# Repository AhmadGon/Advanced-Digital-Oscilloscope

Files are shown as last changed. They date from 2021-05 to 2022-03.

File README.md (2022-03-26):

# Advanced-Digital-Oscilloscope
A new version of digital oscilloscope project that contains debouncers on all buttons and switches, also the ability to make a screenshot and stream it to PC, 2 Channels scope, ability to measure frequencies and amplitudes, pause button and more 

Project implemented on DE2-115 FPGA board

ScopeScreenShot2
ScopeScreenShot
ScopeScreenShot

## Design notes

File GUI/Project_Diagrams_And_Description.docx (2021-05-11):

### Project diagrams and description

# Digital Oscilloscope

### Top Level

Memory

CPU

ADC

VGA

Top Level Module

- VGA driver.
- ADC driver.
- NIOS driver.
- Memory driver:
1. SDRAM
2. M9K SRAM

VGA driver

Vsync/Hsync

Pixel Clock

H_Pixel/V_Pixel

Sync_n/Blank_n

Module exports

Clock/Reset

Module imports

This module imports Clock and reset signals from Top Level module, these signals are then used to generate the necessary Video Graphics Array signals such as Vertical synchronization signal (Vsync) and Horizontal synchronization signal (Hsync), this module also generates a 25MHz pixel clock for displaying 640*480 resolution images at 60Hz refresh rate, no PLL used here since the base frequency of the used FPGA (DE2-115) is 50MHz and we can use a simple counter to generate the 25MHz signal.

The H_Pixel and V_Pixel signals are Horizontal and Vertical counters for scaning the entire monitor frame, these two signals use new terminology than the H_counter/V_counter signals used in the previous Digital Oscilloscope project uploaded on GitHub, the H_Pixel has a range from 0-639 and the V_Pixel has a range from 0-479.

Sync_n/Blank_n active low signals control the ADV7123 DAC to avoid sending data to the blanking area on the screen.

Assigned to Ahmad

### Top Level Description

ADC driver

ADC_CLK

CS

Module exports

Clock/Reset

Module imports

The AD7352 is a differential input, dual ADC intergrated circuit, this dual-ADC has 3MSPS sampling rate with 12-bit accuarcy which is excellent accuarcy,

This ADC needs maximum power supply voltage of 2.75V which is considered low voltage, that means that the power consumption by this ADC is quite low.

The digital oscilloscope is built using based on this ADC

Assigned to Mustafa

Serial_DATA

### Top Level Description

CPU driver

Module exports

Module imports

The NIOS CPU is a soft processor that can be included in any FPGA project, this RISC(Reduced Instruction Set) CPU can be added as an IP Core through Qsys System Integration Tool in Quartus software.

The CPU comes with different cores such as F core and E core for different targets, the E core for example is the economic core drivative of the processor which consume less logic elements and resources but at speed cost.

The NIOS is used in this project as a way to communicate with external PC host to transfer saved data in SDRAM to hard drive, the data stored in SDRAM is screen shot pixel data.

Assigned to Ahmad

### Top Level Description

Memory driver

The memory driver is divided into two main parts, the first one is used to manage the memory within the scope, storing analog data, frequency, images and others, while the second part (the SDRAM part) is specially used to store screen shots, the screen shots should be divided into two parts, the colormap of the image and pixel index for each screen shot or we could just save it as 24-bit data structure which will cost us more memory but in return will make things easier to read by NIOS.

This module has alot of input and output ports with high data trafficing, since every clock pulse plays a major role in controlling data paths that is linked to other modules, we can say that the scope heart is in this module.

No exports and imports are drawn since there are alot of them.

Assigned to Mustafa

Assigned to Ahmad

### Top Level Description

To/From SDRAM

Screen shot order

Incoming data, memory mapped reached

To host PC

Controls ADC chip and recieves serial data form the chip

General Storage

Controls

To Screen

I/O

I/O

ADC

VGA

M9K

Avalon Switch Fabric

SDRAM

NIOS

### General Diagram

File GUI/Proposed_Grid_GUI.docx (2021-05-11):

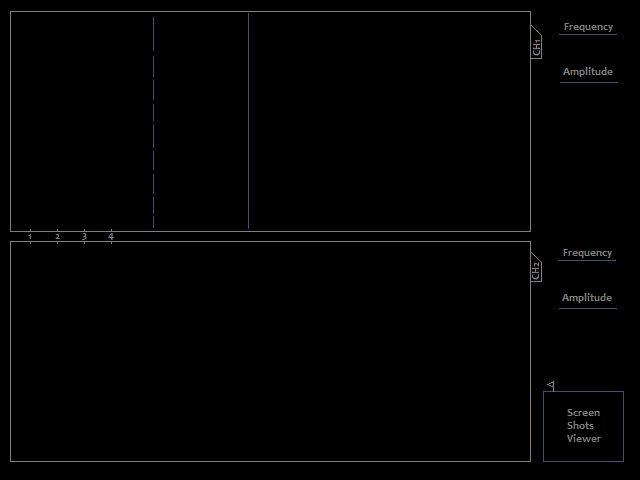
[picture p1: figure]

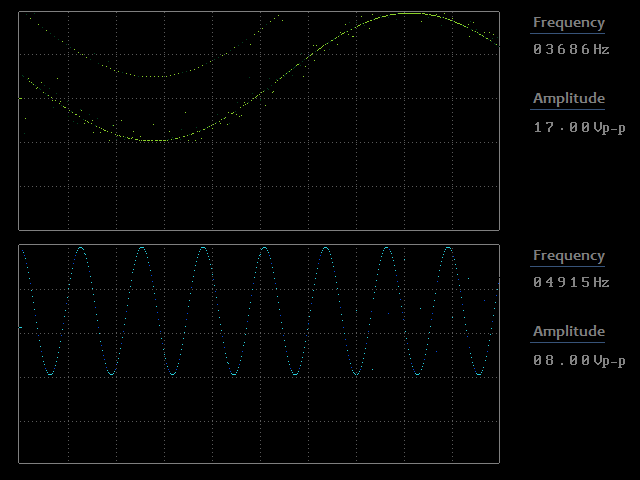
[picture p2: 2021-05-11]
Software/NiosII_Screen_Reader/ScopeScreenShot2.bmp

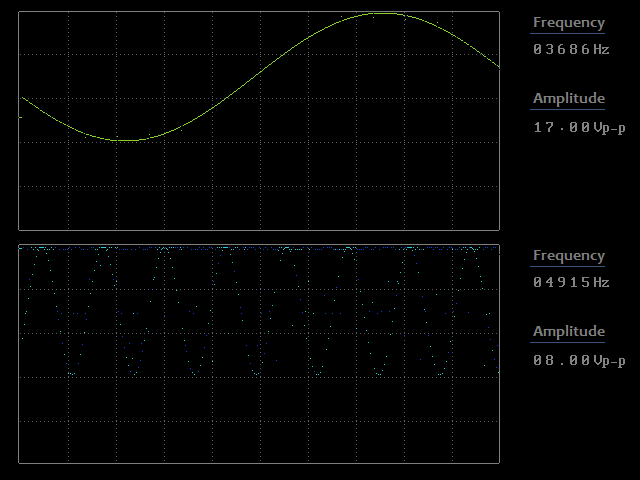
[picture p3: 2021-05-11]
Software/NiosII_Screen_Reader/ScopeScreenShot1.bmp

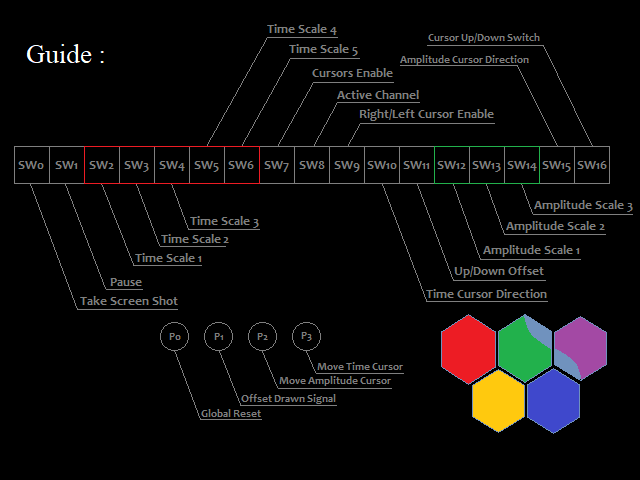
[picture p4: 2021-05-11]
Software/NiosII_Screen_Reader/ScopeScreenShot.bmp

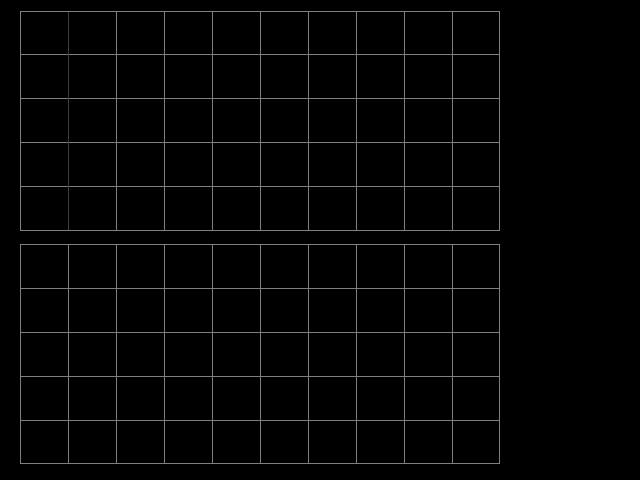
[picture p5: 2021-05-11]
GUI/Proposed_GUI.png

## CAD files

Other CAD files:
db/SRAM_Control_auto_stripped.stp
output_files/stp1.stp
SDRAM_Control.stp
Amplitude_Calculator.stp
db/Amplitude_Calculator_auto_stripped.stp
db/DeBouncer_auto_stripped.stp
TimeScale.stp
db/stp1_auto_stripped.stp
GUI.stp
db/VGA_Controls_auto_stripped.stp
SRAM_Control.stp
db/TimeScale_auto_stripped.stp
DeBouncer.stp
db/GUI_auto_stripped.stp
VGA_Controls.stp
db/SDRAM_Control_auto_stripped.stp

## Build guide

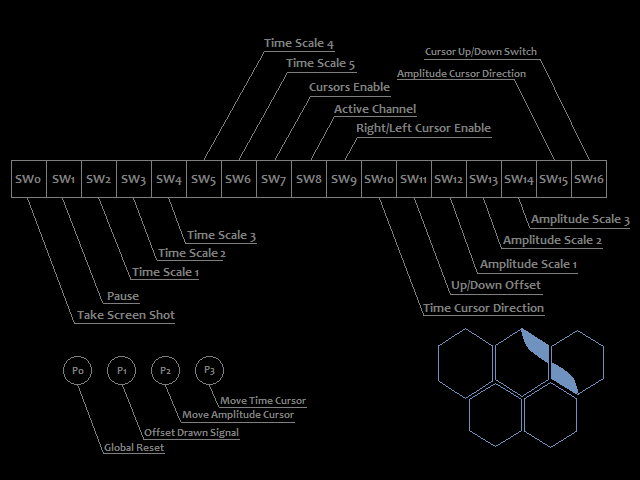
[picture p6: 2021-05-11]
GUI/Guide.png

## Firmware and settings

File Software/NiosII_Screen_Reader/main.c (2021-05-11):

/*
 * Authors: Ahmad Al-Astal, Mustafa Jaber
 */

#include <stdio.h>
#include "system.h"
#include <stdbool.h>
#include "alt_sys_init.c"
#include "altera_avalon_pio_regs.h"
#include "unistd.h"
#include "stdlib.h"

#define getBit(x,y) ((x) & (1 << ((y)-1))) != 0
//	  Write_Finish_Flag = getBit(IORD_ALTERA_AVALON_PIO_DATA(EVENT_REGISTER_BASE), 1);

int main()
{
  printf("Hello from Nios II!\n");
  int Address = 1;
  unsigned int Event_Register = 0;
  unsigned int Response_Register = 0;
  unsigned int Read_Data = 0;
  unsigned int Loading_Percentage = 0;
  char Read_Data_Characters[24];
  FILE* pScreenFile = NULL;

  while(1)
  {
	  /** Event_Register reads some external events happened outside Nios domain, such as WriteFinish_Flag */
	  Event_Register = IORD_ALTERA_AVALON_PIO_DATA(EVENT_REGISTER_BASE);

	  /** Create a .txt file to save pixel data to */
	  if (pScreenFile == NULL)
	  {
		  pScreenFile = fopen("/mnt/host/ScreenShot.txt", "w");
	  }

	  /** If writing to SRAM event is finished and no previous Nios response is detected then initiate a new reading event from Nios */
	  if (Event_Register > 0 && Response_Register == 0)
	  {
		  IOWR_ALTERA_AVALON_PIO_DATA(ADDRESS_BASE, Address);
		  Read_Data = IORD_ALTERA_AVALON_PIO_DATA(DATA_BASE);
		  IOWR_ALTERA_AVALON_PIO_DATA(LOADING_PERCENTAGE_BASE, Loading_Percentage);

		  itoa(Read_Data, Read_Data_Characters, 10);
		  fprintf(pScreenFile,"%s\n", Read_Data_Characters);

		  Address++;
		  Loading_Percentage = ((float)Address / 614399) * 100;
		  /** After finish streaming the data stored in SRAM, Nios will response to this by raising the Nios_Finish_Reading_Flag and setting the reading address again */
		  /** to zero to prepare for future reading events */
		  if (Address == 614399) //614399
		  {
			  Response_Register = 1;
			  IOWR_ALTERA_AVALON_PIO_DATA(RESPONSE_REGISTER_BASE, Response_Register);

			  /** Reset the address and write the reseted address to the address bus */
			  Address = 1;
			  IOWR_ALTERA_AVALON_PIO_DATA(ADDRESS_BASE, Address);
			  fclose(pScreenFile);
		  }
	  }
	  /** The external WriteFinish_Flag must be set to zero to begin new writing event to SRAM, in other words a new ScreenShot order is be given */
	  else if (Event_Register == 0)
	  {
		  Response_Register = 0;
		  pScreenFile = NULL;
		  IOWR_ALTERA_AVALON_PIO_DATA(RESPONSE_REGISTER_BASE, Response_Register);
	  }
  }
  return 0;
}

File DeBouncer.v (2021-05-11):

//================================================================
//     DeBouncer Module
//		 
//		 This module is responsible for debouncing switching events
//		 in other words wait enough time for the input switch/push
//		 button to settle down to stable state before taking its 
//		 value
//================================================================
module DeBouncer(
	input Main_CLK, 
	/** Bounced input pins */
	input Reset, ScreenCapture, Pause, TimeScale_1, TimeScale_2, TimeScale_3, TimeScale_4, TimeScale_5, Cursors_Enable,
	input Cursor_Channel_Switch, Cursor_Right_Left_Switch, Cursor_Direction_Switch, Cursor_Moving_Button,
	input Move_Up_Down_Drawn_Signal, Signal_Move_Button, Cursor_Up_Down_Switch, Amplitude_Cursor_Direction_Switch,
	input Amplitude_Cursor_Moving_Button,
	input [2:0] Amplitude_Binary,
	input Guide,
	/** Debounced output signals */
	output ScreenCapture_Activated, Pause_Activated, Reset_Activated, TimeScale_1_Activated, TimeScale_2_Activated, TimeScale_3_Activated,
	output TimeScale_4_Activated, TimeScale_5_Activated, Cursor_Channel_Switch_Activated, Cursor_Right_Left_Switch_Activated,
	output Cursor_Direction_Switch_Activated, Cursor_Moving_Button_Activated, Cursors_Enable_Activated,
	output Move_Up_Down_Drawn_Signal_Activated, Signal_Move_Button_Activated, Cursor_Up_Down_Switch_Activated,
	output Amplitude_Cursor_Direction_Switch_Activated, Amplitude_Cursor_Moving_Button_Activated,
	output [2:0] Amplitude_Binary_Activated,
	output Guide_Activated
);

/* Note: To add a new debouncer for your switch follow the below steps:
 * 		1. Declare a 13-bit debouncer counter for your switch.
 *			2. Name the output of the debouncer (SwithcName_Activated).
 *			3. Copy the first always block with doing name changes to be
 *			   compatible with your switch.
 */
assign ScreenCapture_Activated = ScreenCapture_Flag;
assign Pause_Activated = Pause_Flag;
assign Reset_Activated = !Reset_Flag;
assign TimeScale_1_Activated = TimeScale_1_Flag;
assign TimeScale_2_Activated = TimeScale_2_Flag;
assign TimeScale_3_Activated = TimeScale_3_Flag;
assign TimeScale_4_Activated = TimeScale_4_Flag;
assign TimeScale_5_Activated = TimeScale_5_Flag;
assign Cursor_Channel_Switch_Activated = Cursor_Channel_Switch_Flag;
assign Cursor_Right_Left_Switch_Activated = Cursor_Right_Left_Switch_Flag;
assign Cursor_Direction_Switch_Activated = Cursor_Direction_Switch_Flag;
assign Cursor_Moving_Button_Activated = Cursor_Moving_Button_Flag;
assign Cursors_Enable_Activated = Cursors_Enable_Flag;
assign Move_Up_Down_Drawn_Signal_Activated = Move_Up_Down_Drawn_Signal_Flag;
assign Signal_Move_Button_Activated = Signal_Move_Button_Flag;
assign Cursor_Up_Down_Switch_Activated = Cursor_Up_Down_Switch_Flag;
assign Amplitude_Cursor_Direction_Switch_Activated = Amplitude_Cursor_Direction_Switch_Flag;
assign Amplitude_Cursor_Moving_Button_Activated = Amplitude_Cursor_Moving_Button_Flag;
assign Amplitude_Binary_Activated = Amplitude_Binary_Flag;
assign Guide_Activated = Guide_Flag;

reg ScreenCapture_Flag, Pause_Flag, Reset_Flag, TimeScale_1_Flag, TimeScale_2_Flag, TimeScale_3_Flag, TimeScale_4_Flag, TimeScale_5_Flag;
reg Cursor_Channel_Switch_Flag, Cursor_Right_Left_Switch_Flag, Cursor_Direction_Switch_Flag, Cursor_Moving_Button_Flag;
reg Cursors_Enable_Flag, Move_Up_Down_Drawn_Signal_Flag, Signal_Move_Button_Flag, Cursor_Up_Down_Switch_Flag;
reg Amplitude_Cursor_Direction_Switch_Flag, Amplitude_Cursor_Moving_Button_Flag, Guide_Flag;
reg [2:0] Amplitude_Binary_Flag;
//====================================
/** Debouncer for ScreenCapture switch */
reg[12:0] ScreenCaptureDeBounce_Counter;
always @(posedge Main_CLK)
	begin
	if (!Reset_Activated) ScreenCapture_Flag <= 0;
	else
		begin
		if (ScreenCapture && !ScreenCapture_Flag)
			begin
			ScreenCaptureDeBounce_Counter <= ScreenCaptureDeBounce_Counter + 1;
			if (ScreenCaptureDeBounce_Counter == 7999) ScreenCapture_Flag <= 1;
			else ScreenCapture_Flag <= 0;
			end
		else if (!ScreenCapture) 
			begin
			ScreenCapture_Flag <= 0;
			ScreenCaptureDeBounce_Counter <= 0;
			end
		else ScreenCaptureDeBounce_Counter <= 0;
		end
	end
//====================================
/** Debouncer for Pause switch */
reg[12:0] PauseDeBounce_Counter;
always @(posedge Main_CLK)
	begin
	if (!Reset_Activated) Pause_Flag <= 0;
	else
		begin
		if (Pause && !Pause_Flag)
			begin
			PauseDeBounce_Counter <= PauseDeBounce_Counter + 1;
			if (PauseDeBounce_Counter == 7999) Pause_Flag <= 1;
			else Pause_Flag <= 0;
			end
		else if (!Pause) 
			begin
			Pause_Flag <= 0;
			PauseDeBounce_Counter <= 0;
			end
		else PauseDeBounce_Counter <= 0;
		end
	end
//====================================
/** Debouncer for Reset switch */
reg[12:0] ResetDeBounce_Counter;
always @(posedge Main_CLK)
	begin
	if (!Reset && !Reset_Flag)
		begin
		ResetDeBounce_Counter <= ResetDeBounce_Counter + 1;
		if (ResetDeBounce_Counter == 7999) Reset_Flag <= 1;
		else Reset_Flag <= 0;
		end
	else if (Reset) 
		begin
		Reset_Flag <= 0;
		ResetDeBounce_Counter <= 0;
		end
	else ResetDeBounce_Counter <= 0;
	end
//====================================
/** Debouncer for TimeScale_1 switch */
reg[12:0] TimeScale_1_DeBounce_Counter;
always @(posedge Main_CLK)
	begin
	if (!Reset_Activated) TimeScale_1_Flag <= 0;
	else
		begin
		if (TimeScale_1 && !TimeScale_1_Flag)
			begin
			TimeScale_1_DeBounce_Counter <= TimeScale_1_DeBounce_Counter + 1;
			if (TimeScale_1_DeBounce_Counter == 7999) TimeScale_1_Flag <= 1;
			else TimeScale_1_Flag <= 0;
			end
		else if (!TimeScale_1) 
			begin
			TimeScale_1_Flag <= 0;
			TimeScale_1_DeBounce_Counter <= 0;
			end
		else TimeScale_1_DeBounce_Counter <= 0;
		end
	end
//====================================
/** Debouncer for TimeScale_2 switch */
reg[12:0] TimeScale_2_DeBounce_Counter;
always @(posedge Main_CLK)
	begin
	if (!Reset_Activated) TimeScale_2_Flag <= 0;
	else
		begin
		if (TimeScale_2 && !TimeScale_2_Flag)
			begin
			TimeScale_2_DeBounce_Counter <= TimeScale_2_DeBounce_Counter + 1;
			if (TimeScale_2_DeBounce_Counter == 7999) TimeScale_2_Flag <= 1;
			else TimeScale_2_Flag <= 0;
			end
		else if (!TimeScale_2) 
			begin
			TimeScale_2_Flag <= 0;
			TimeScale_2_DeBounce_Counter <= 0;
			end
		else TimeScale_2_DeBounce_Counter <= 0;
		end
	end
//====================================
/** Debouncer for TimeScale_3 switch */
reg[12:0] TimeScale_3_DeBounce_Counter;
always @(posedge Main_CLK)
	begin
	if (!Reset_Activated) TimeScale_3_Flag <= 0;
	else
		begin
		if (TimeScale_3 && !TimeScale_3_Flag)
			begin
			TimeScale_3_DeBounce_Counter <= TimeScale_3_DeBounce_Counter + 1;
			if (TimeScale_3_DeBounce_Counter == 7999) TimeScale_3_Flag <= 1;
			else TimeScale_3_Flag <= 0;
			end
		else if (!TimeScale_3) 
			begin
			TimeScale_3_Flag <= 0;
			TimeScale_3_DeBounce_Counter <= 0;
			end
		else TimeScale_3_DeBounce_Counter <= 0;
		end
	end
//====================================
/** Debouncer for TimeScale_4 switch */
reg[12:0] TimeScale_4_DeBounce_Counter;
always @(posedge Main_CLK)
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
